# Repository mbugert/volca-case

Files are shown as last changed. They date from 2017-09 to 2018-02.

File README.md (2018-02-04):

# Volca Case
Laser-cut transport case and dust protector for all Korg Volca synthesizers. Made with OpenSCAD.

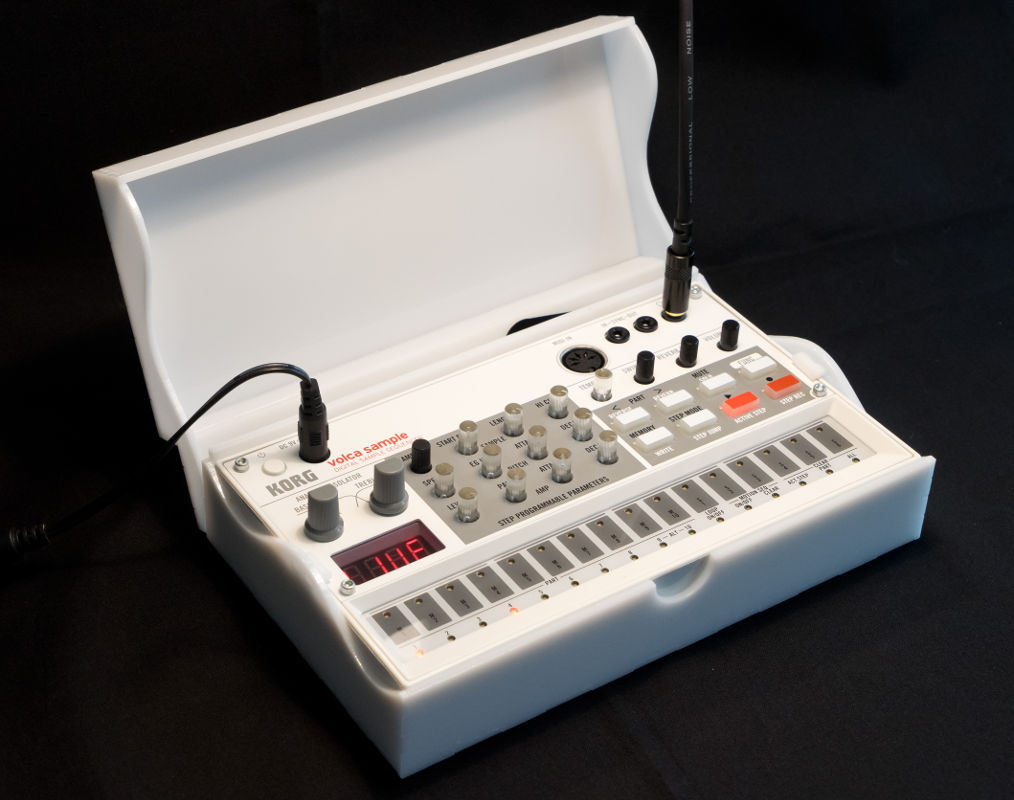
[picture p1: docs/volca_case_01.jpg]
Volca Case


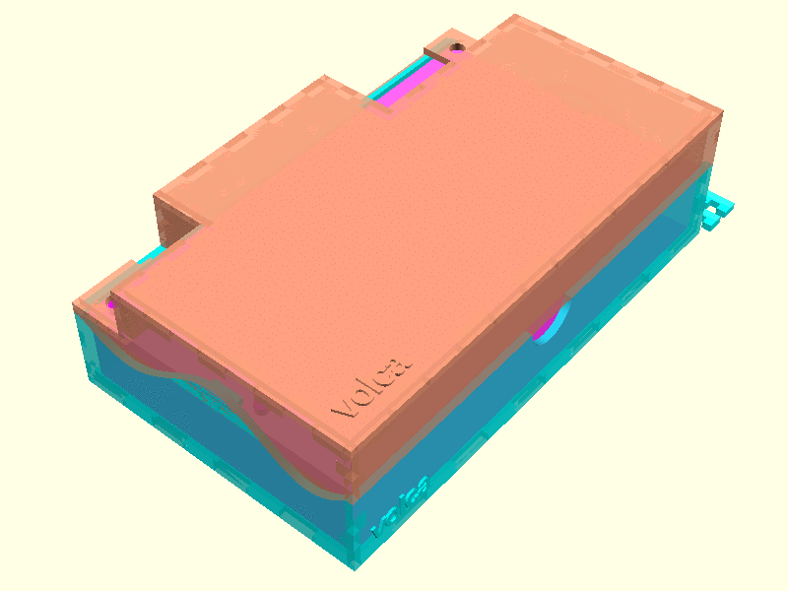
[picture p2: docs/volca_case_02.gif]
Volca Case Family


The lid can be removed without unplugging any cables:
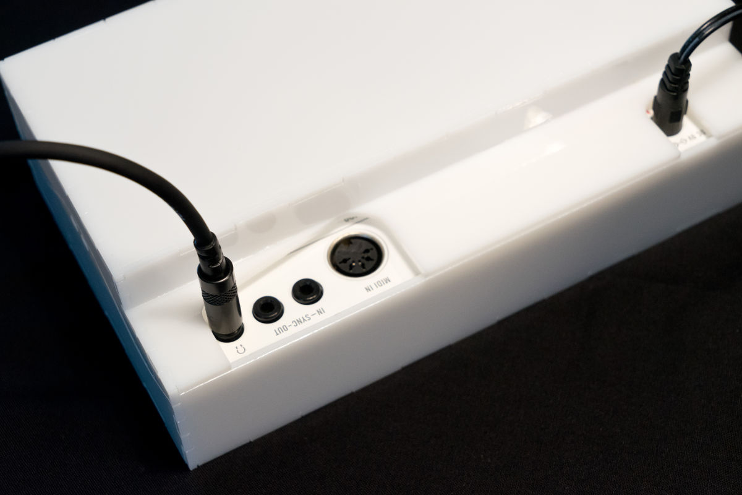
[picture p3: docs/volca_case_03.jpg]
Volca Case


## How to build one
Download pre-made 2D templates [from the releases page](https://github.com/mbugert/volca-case/releases) or customize and create your own template (see below). Then, feed the template to a lasercutter and assemble the case using some glue.
If you don't know where to lasercut, check the internet to find a nearby FabLab/Makerspace which owns a lasercutter.

## How to customize
Multiple things about the case can be customized, such as:
* case thickness
* laser kerf compensation
* larger cutouts to accomodate space for bulky plugs
* disabling cutouts in the lid altogether

The case is made with OpenSCAD. You will need to install:
* [OpenSCAD](http://www.openscad.org/), version 2015.03
* the [lasercut](https://github.com/bmsleight/lasercut) library
* the (**linux only!**) [laserscad](https://github.com/mbugert/laserscad/) library, at least version 0.3.x

Once these are set up, you can customize the case by changing stuff in ``src/modules/case_settings.scad``. Then, follow the instructions at "Exporting to 2D" in the [laserscad readme](https://github.com/mbugert/laserscad/blob/master/README.md) to create your 2D template.

Alternatively, to export the case for all Volca units and materials of various thicknesses, additionally install ``imagemagick`` and follow the instructions in ``make-case``.

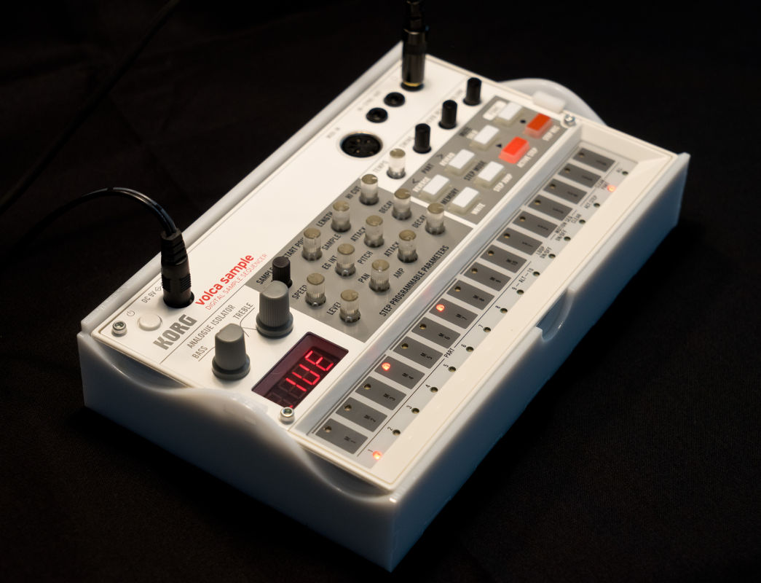
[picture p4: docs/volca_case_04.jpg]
Volca Case


Volca Case in action

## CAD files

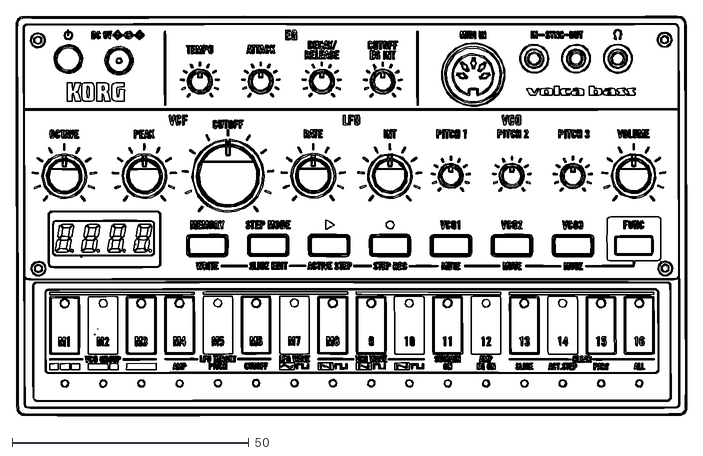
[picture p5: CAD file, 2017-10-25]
src/img/bass.dxf
141.7 x 84.4

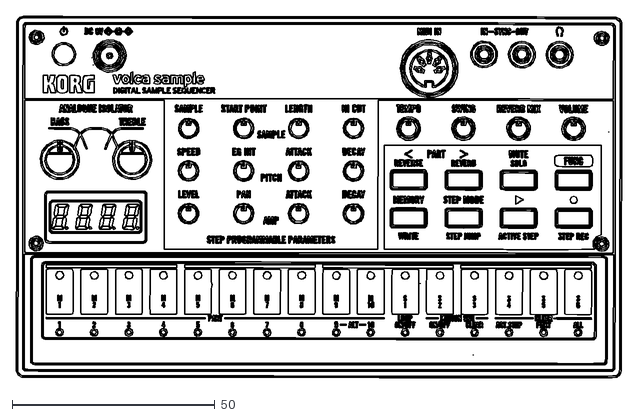
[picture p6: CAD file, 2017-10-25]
src/img/sample.dxf
149.3 x 89.1

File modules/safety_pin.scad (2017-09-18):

include <laserscad.scad>
include <lasercut.scad>

include <case_dimensions.scad>


module safety_pin(id) {
    x = safety_pin_inner_xlen;
    y = safety_pin_ylen;

    ltranslate([-t, -0.5*y, 0])
        lpart(id, [x+t,y])
            translate([t,0,0]) {
                cube([x, y, t]);
                fingerJoint(LEFT, 1, 2, t, 4/3 * y, 0, x, 0, true);
            }
}
module safety_pin_cutout() {
    x = safety_pin_inner_xlen;
    y = safety_pin_ylen;
    dif = 1;
    
    translate([-dif,-0.5*y,0])
        fingerJoint(LEFT, 1, 2, t, 4/3 * y, 0, x, 0, false);
}

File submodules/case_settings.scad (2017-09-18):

// ############### SETTINGS #################

// CHOOSE YOUR FLAVOR:
// 0: one size fits all (currently not supported)
// 1: beats
// 2: bass (currently not supported)
// 3: keys (currently not supported)
// 4: sample
// 5: fm (currently not supported)
// 6: kick (currently not supported)
unit = 4;

// leave holes in the lid for power, MIDI and audio jacks? (so that the lid can be put on without having to unplug everything)
cutouts_for_io_jacks = true;

// create holes for magnets which hold the lid in place?
cutouts_for_magnetic_lid = false;

// magnet dimensions in millimeters - magnet_xlen is assumed to be equal to the shell thickness, i.e. use 5mm wide magnets if you set thickness to 5mm
magnet_ylen = 5;
magnet_zlen = 2;

// safety distance between jacks and case in millimeters - increase this if you use cables with bulky plugs
jack_r_padding = 1.5;

// sheet thickness in millimeters (5mm max due to the MIDI jack and neighboring potis; maybe 6mm if you own a MIDI cable with a very slim plug)
thickness = 3;

// laser kerf compensation in millimeters
lkerf = 0.05; // 3mm PMMA in Epilog Zing with 25% speed, 50% power, 5000Hz laser

// separation of parts in 2D in millimeters
lmargin = 2;

// in case the material you laser from has a distinguishable top/bottom side, mirror the following lparts: bottom_case_right, bottom_case_back, bottom_case_bottom, lid_right, lid_back

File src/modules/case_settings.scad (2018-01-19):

// Copyright 2018, mbugert
// 
// This program is free software: you can redistribute it and/or modify
// it under the terms of the GNU General Public License as published by
// the Free Software Foundation, either version 3 of the License, or
// (at your option) any later version.
// 
// This program is distributed in the hope that it will be useful,
// but WITHOUT ANY WARRANTY; without even the implied warranty of
// MERCHANTABILITY or FITNESS FOR A PARTICULAR PURPOSE.  See the
// GNU General Public License for more details.
// 
// You should have received a copy of the GNU General Public License
// along with this program.  If not, see <http://www.gnu.org/licenses/>.

// ############### SETTINGS #################

// CHOOSE YOUR FLAVOR:
// 0: one size fits all
// 1: beats
// 2: bass
// 3: keys
// 4: sample
// 5: fm
// 6: kick
unit = 0;

// leave holes in the lid for power, MIDI and audio jacks? (so that the lid can be put on without having to unplug everything)
cutouts_for_io_jacks = true;

// add line-art engravings on the lid (if available) and the name of the unit on the bottom (and more)?
engravings = true;

// engrave the values of the most important settings into the bottom of the base? (useful when experimenting with parameters; also generated when engravings = false)
debug_engravings = false;

// safety distance between jacks and case in millimeters - increase this if you use cables with bulky plugs
jack_r_padding = 1.5;

// sheet thickness in millimeters (5mm max due to the MIDI jack and neighboring potis; maybe 6mm if you own a MIDI cable with a very slim plug)
thickness = 3;

// laser kerf compensation in millimeters
lkerf = 0.05; // 2.5mm PMMA in Epilog Zing with 25% speed, 50% power, 5000Hz laser

// separation of parts in 2D in millimeters
lmargin = 2;

// don't engrave parts with their ID
lidentify = false;

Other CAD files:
submodules/safety_pin.scad
modules/bottom/bottom_case.scad
modules/bottom_case.scad
modules/lid/unobstructed_back.scad
src/modules/base/base.scad
src/modules/base/base_dimensions.scad
src/modules/base/safety_pin.scad
src/modules/case_dimensions.scad
src/modules/engravings.scad
src/modules/lid/io_cutouts.scad
src/modules/lid/lid.scad
src/modules/lid/lid_back_free.scad
src/modules/lid/lid_back_obstructed.scad
src/modules/lid/lid_dimensions.scad
src/modules/volca_dimensions.scad
src/modules/volca_unit.scad
src/volca_case.scad
submodules/bottom_case.scad
submodules/case_dimensions.scad
submodules/lid.scad

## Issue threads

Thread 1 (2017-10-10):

Fix educated guesses in volca dimensions

mbugert, 2017-10-10:
In [volca_dimensions.scad](https://github.com/mbugert/volca-case/blob/master/src/modules/volca_dimensions.scad), measure with a caliper:
- [ ] rubber_feet_zlen
- [ ] tworow_ribbon_ylen
- [ ] large_poti_zlen
- [ ] max_poti_zlen_by_unit for FM

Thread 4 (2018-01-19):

Upgrade to laserscad 0.3.0

mbugert, 2018-01-19:
SVG modifications from 0.2.1 will fix the outline issues with line art engravings.

mbugert, 2018-02-04:
Change to 0.3.0 because of newly introduced version checks in laserscad.

mbugert, 2018-02-04:
Done.

Closed 2018-02-04.

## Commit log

2017-09-18 Initial commit. Case ready for 3mm PMMA laser.
    [korg_volca_case.scad, korg_volca_dimensions.scad]
2017-09-18 Refactoring: modularize.
    [bottom_case.scad, case_dimensions.scad, case_settings.scad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]
2017-09-18 More modularization.
    [bottom_case.scad, case_dimensions.scad, case_settings.scad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]
2017-09-18 Lid code modularization.
    [lid.scad]
2017-09-18 Lid modularized.
    [bottom_case.scad, io_cutouts.scad, korg_volca_case.scad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]
2017-09-18 Still refactoring the lid.
    [case_dimensions.scad, lid.scad, lid_back_free.scad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]
2017-09-18 Fix structural weakness near MIDI jack in io_cutouts.
    [io_cutouts.scad]
2017-09-18 WIP on obstructed back support.
    [lid_back_obstructed.scad, lid_dimensions.scad]
2017-09-18 WIP on full family.
    [lid_back_obstructed.scad]
2017-09-18 Lid finger joints refactored to fix weak structure in right lid side.
    [lid.scad, lid_back_free.scad, lid_back_obstructed.scad]
2017-09-18 Full volca family support complete.
    [case_dimensions.scad, case_settings.scad, korg_volca_case.scad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]
2017-09-18 Refactor name of bottom part to "base".
    [base.scad, korg_volca_case.scad, safety_pin.scad]
2017-09-18 Remove debug command. $fn=100, unit=0.
    [case_dimensions.scad, case_settings.scad, korg_volca_case.scad]
2017-09-19 Modularize base.
    [base.scad, base_dimensions.scad]
2017-09-19 Safety pin kerf variants.
    [base.scad, case_dimensions.scad, safety_pin.scad]
2017-09-19 Panel screw cutouts in bezel covers.
    [case_dimensions.scad, io_cutouts.scad, lid_back_free.scad]
2017-09-22 Fix bounding boxes. Better lpart names for safety pin variants.
    [base.scad, lid_back_obstructed.scad]
2017-09-27 Engrave name of volca unit on lid and base.
    [base.scad, case_dimensions.scad, case_settings.scad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]
2017-09-27 More engravings.
    [base.scad, case_dimensions.scad, case_settings.scad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]
2017-09-27 Fix that disabling IO cutouts would also disable panel screw cutouts.
    [io_cutouts.scad, lid_back_free.scad]
2017-09-30 Makefile for compiling releases. Move model code into src subfolder.
    [base.scad, base_dimensions.scad, case_dimensions.scad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]
2017-10-09 Replicate changes in laserscad API.
    [base.scad, lid_back_free.scad, lid_back_obstructed.scad]
2017-10-10 Makefile creates PNG renders and GIF of case variants.
    [case_settings.scad, korg_volca_case.scad, volca_dimensions.scad]
2017-10-10 Fixes for high thickness models (safety pins, case wave and weak structure in lid sides).
    [case_dimensions.scad, safety_pin.scad]
2017-10-12 Rename main file.
    [volca_case.scad]
2017-10-23 #1 Add two measurements from volca bass and one from volca fm (thanks to /u/polyeurothang).
    [volca_dimensions.scad]
2017-10-23 Fix excessive finger joint in the lid for bass, fm, kick, keys.
    [lid_back_obstructed.scad]
2017-10-25 Remove legacy code for magnetic lid.
    [base.scad, case_dimensions.scad, case_settings.scad]
2017-10-25 Add prominent mention of lasercutting in readme.
2017-10-25 Mild fix for panel_screw_back_y.
    [volca_dimensions.scad]
2017-10-25 Add support for line art engravings and line art for sample and bass.
    [bass.dxf, case_settings.scad, engravings.scad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]
2017-10-26 Fix wrong import statement for beats, sample.
    [lid_back_free.scad]
2018-01-19 #3 - Add license headers
    [base.scad, base_dimensions.scad, case_dimensions.scad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]
2018-02-04 Remove unused text_on library.
    [case_dimensions.scad]
2018-02-04 #4 - Upgrade to laserscad 0.3.x: Add lassert_version and adjust README
    [volca_case.scad]
